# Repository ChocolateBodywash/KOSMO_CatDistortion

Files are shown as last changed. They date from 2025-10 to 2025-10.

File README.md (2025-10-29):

## KOSMO Format Cat Distortion 

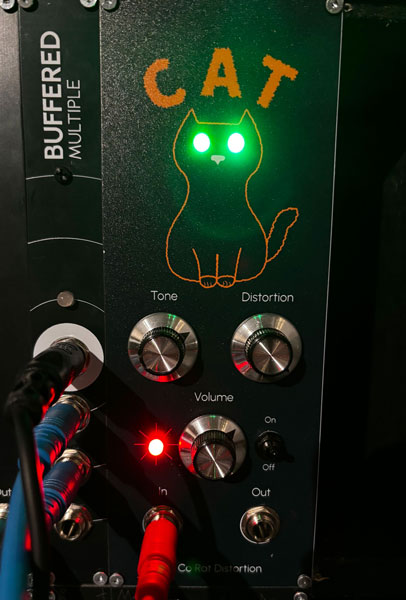
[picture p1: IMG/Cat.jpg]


A KOSMO format of a PROCO Rat distortion pedal.

I love the PROCO RAT Distortion, so I adapted it for Synth DIY.

I’ve always loved the RAT, so I reworked it for Synth DIY. If you want the deep dive into how the circuit works, check out this excellent breakdown:
https://www.electrosmash.com/proco-rat

For this version, I swapped the original op-amp for a more common TL072. The clipping circuit also got an upgrade, the diodes were replaced with LEDs, which double as glowing cat eyes on the panel. They're actually part of the circuit, not just for show. Different colours will have different forward voltages and thus may effect the sound (although I haven't tested this).

The front panel design was created using JLCPCB's colour silkscreen option, which is only avalible with easyEDA. My Kicad files are just one static colour.

Note: Because I'm not entirely sure what I'm doing, the maximum output level might be a bit much. This has a useful side effect though, it can bring guitar level to synth level.

---
Note: This was created by a hobbyist with no formal engineering training outside various late night YouTube binges. 
I’ve confirmed these designs to work but I make no guarantees on the design working efficiently.. or working at all.

Additional credit: Analog Output (Richard Holmes) for footprint libraries and front panel templates.

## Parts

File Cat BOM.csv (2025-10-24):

Reference | Value | Datasheet | Package | Qty
C1,C2 | 47uF | ~ | Electrolytic Capacitor | 2
C3,C4,C5,C6 | 0.1uF | ~ | Ceramic Disc Capacitor | 4
C7,C9 | 4.7uF | ~ | Electrolytic Capacitor | 2
C8 | 100pf | ~ | Ceramic Disc Capacitor | 1
C10 | 1nF | ~ | Box Style Film Capacitor | 1
C11,C15 | 1uF | ~ | Electrolytic Capacitor | 3
C17 | 1uF | ~ | Box Style Film Capacitor
C12,C14 | 22nF | ~ | Box Style Film Capacitor | 2
C13 | 3.3nF | ~ | Box Style Film Capacitor | 1
C16 | 2.2uF | ~ | Electrolytic Capacitor | 1
C18 | 47pF | ~ | Ceramic Disc Capacitor | 1
D1,D2 | 1N5819 | http://www.vishay.com/docs/88525/1n5817.pdf | Diode_THT:D_DO-41_SOD81_P10.16mm_Horizontal | 2
D3,D4,D5 | LED | ~ | LED 5.0mm (I used green for the eyes. These are part of the cliping stage different colours may have different effects) | 3
E1 | Conn_02x05_Pin | ~ | Pins_2x05_2.54mm_TH_EurorackPower_Shrouded | 1
J1 | In | ~ | Jack_6.35mm | 1
J2,J3 | Conn_01x06 | ~ | Connector_PinHeader_2.54mm:PinHeader_1x06_P2.54mm_Vertical | 2
J4 | Out | ~ | Jack_6.35mm | 1
Q2 | 2N5458 | https://my.centralsemi.com/datasheets/2N3819.PDF | Package_TO_SOT_THT:TO-92L_Inline_Wide | 1
R1,R2 | 10 | ~ | Metal Film 1/4 Resistor | 2
R3 | 560 | ~ | Metal Film 1/4 Resistor | 1
R4,R9,R19,R20,R22 | 1K | ~ | Metal Film 1/4 Resistor | 5
R5,R8,R11 | 1M | ~ | Metal Film 1/4 Resistor | 3
R6,R7,R14,R15 | 100K | ~ | Metal Film 1/4 Resistor | 4
R10 | 1.5K | ~ | Metal Film 1/4 Resistor | 1
R12,R17 | 10K | ~ | Metal Film 1/4 Resistor | 2
R13 | 47 | ~ | Metal Film 1/4 Resistor | 1
R16 | 3K | ~ | Metal Film 1/4 Resistor | 1
R18 | 470R | ~ | Metal Film 1/4 Resistor | 1
R21 | 22K | ~ | Metal Film 1/4 Resistor | 1
SW1 | SW_DPDT_x2 | ~ | DPDT switch | 1
U1 | TL072 | http://www.ti.com/lit/ds/symlink/tl071.pdf | DIP-8_W7.62mm | 1
VR1 | A100K Dist | ~ | Potentiometer_Alpha_RD901F-40-00D_Single_Vertical | 1
VR2 | A100K Tone | ~ | Potentiometer_Alpha_RD901F-40-00D_Single_Vertical | 1
VR3 | A100K Vol | ~ | Potentiometer_Alpha_RD901F-40-00D_Single_Vertical | 1

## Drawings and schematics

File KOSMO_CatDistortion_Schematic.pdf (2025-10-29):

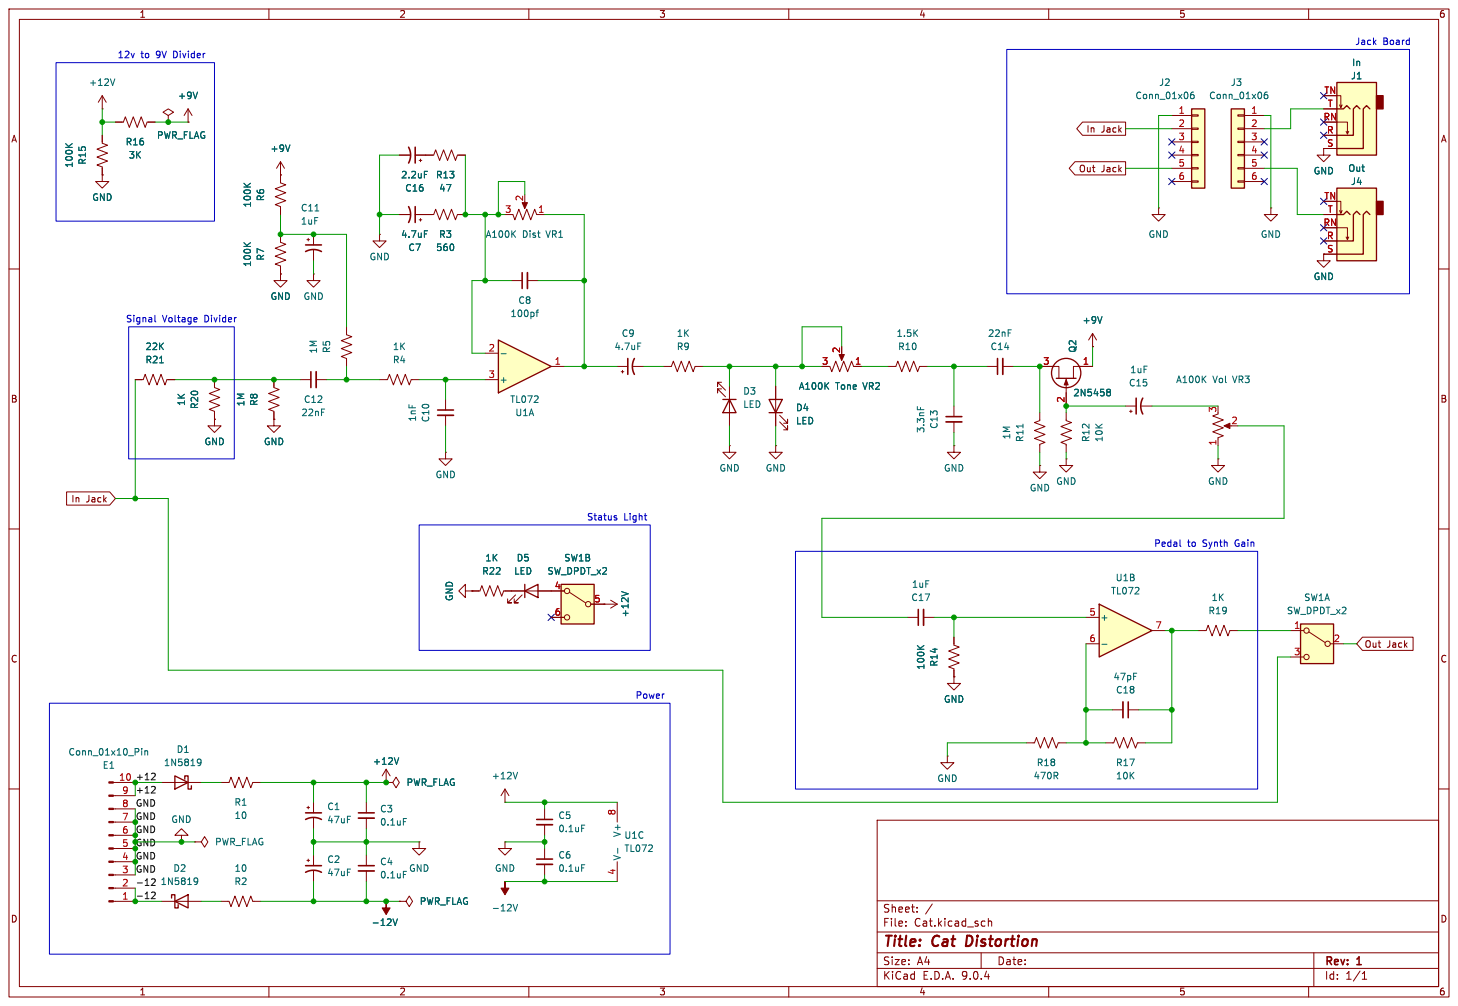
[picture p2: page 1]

Jack Board Pedal to Synth Gain
J4 Out C18

In Jack GND GND GND
PWR_FLAG R16

File: Cat.kicad_sch Sheet: /
Id: 1/1 Title: Cat Distortion

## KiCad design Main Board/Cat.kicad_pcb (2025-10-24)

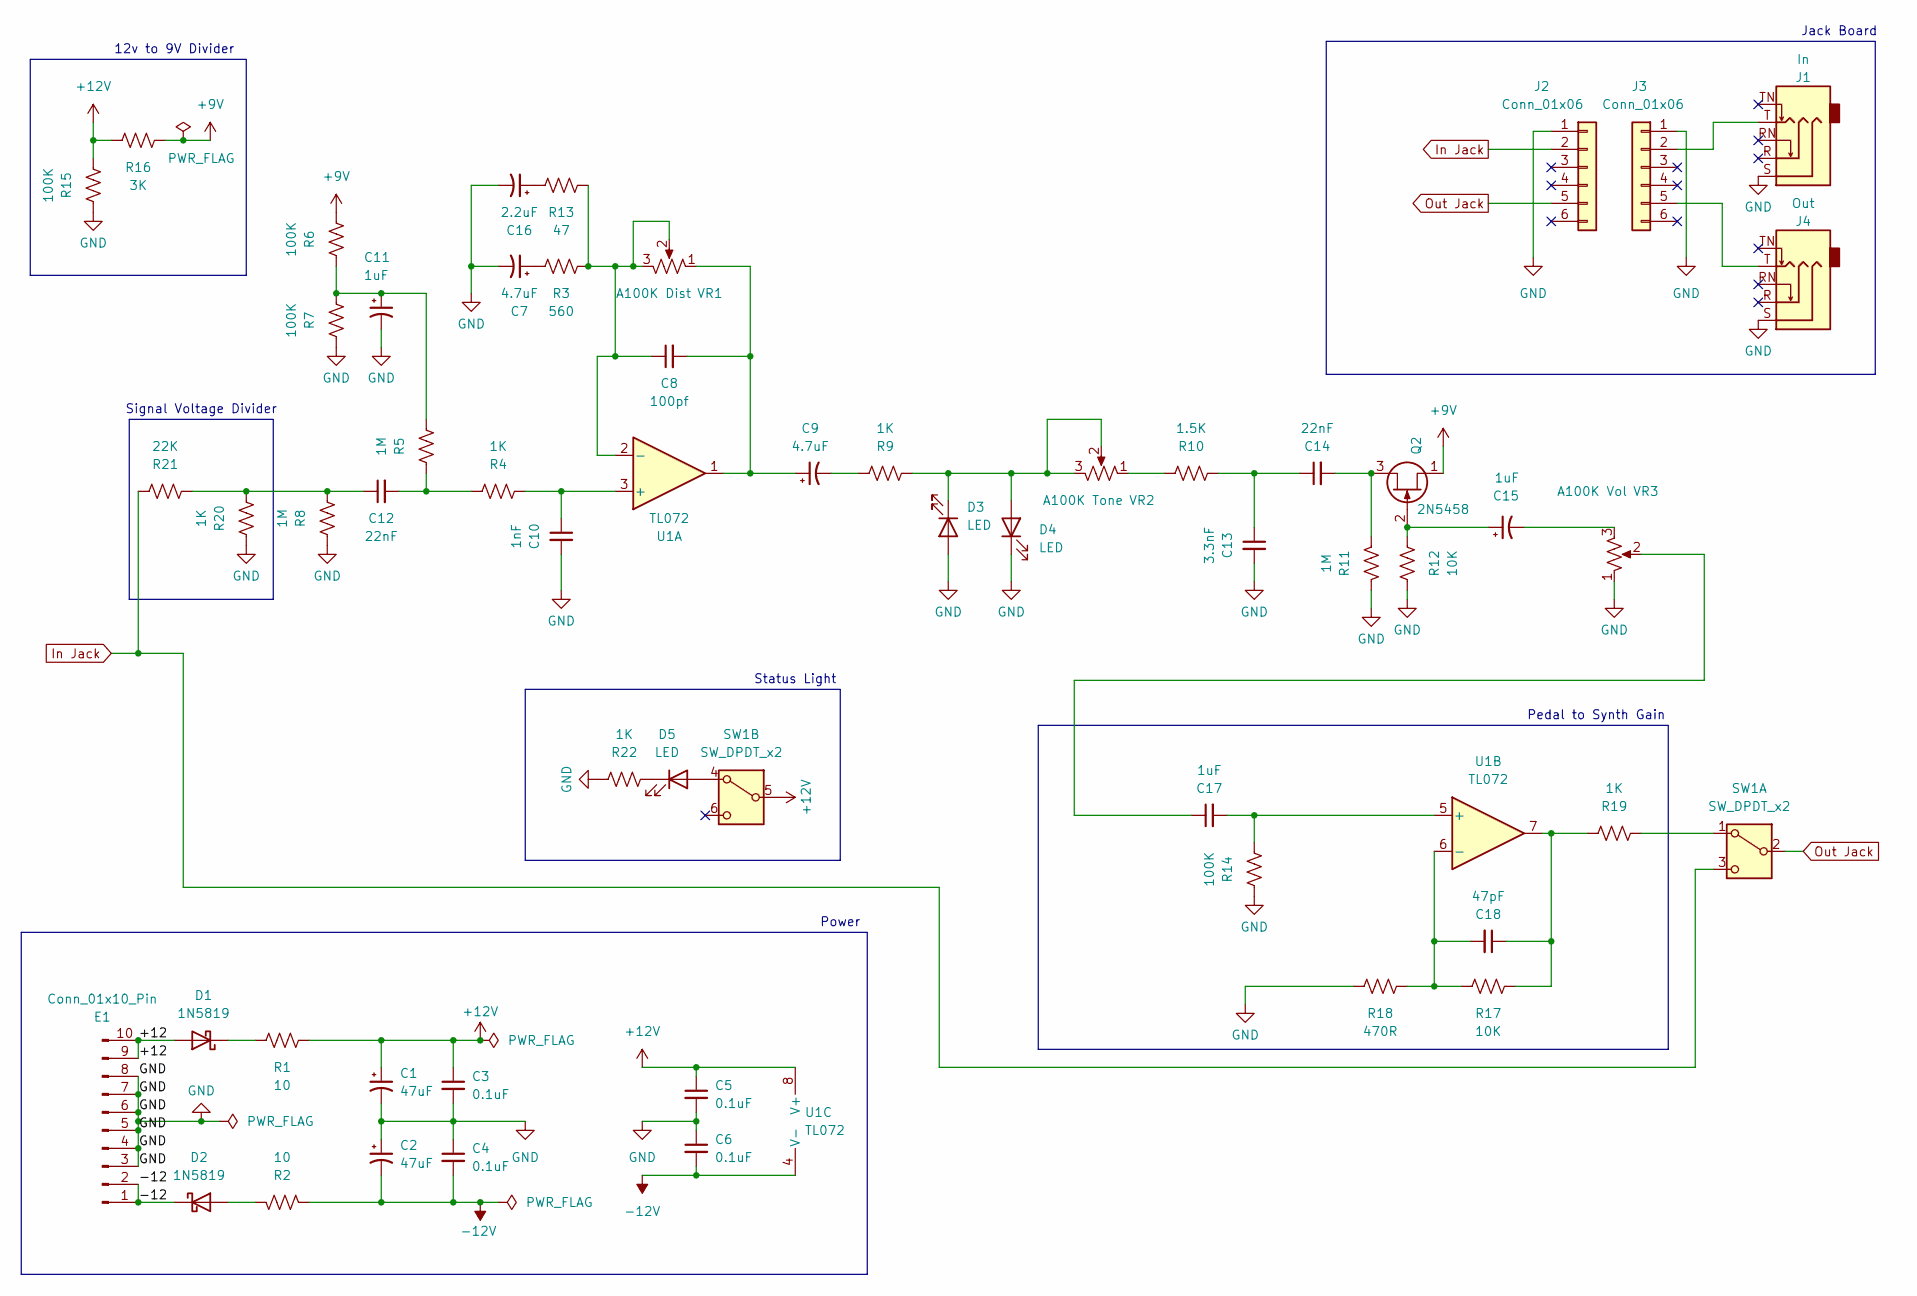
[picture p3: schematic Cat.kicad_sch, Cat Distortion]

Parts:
C1, C2: 47uF; CP_Radial_D5.0mm_P2.50mm
C3, C4, C5, C6: 0.1uF; C_Disc_D3.0mm_W1.6mm_P2.50mm
C7, C9: 4.7uF; CP_Radial_D5.0mm_P2.50mm
C8: 100pf; C_Disc_D3.0mm_W1.6mm_P2.50mm
C10: 1nF; C_Rect_L7.2mm_W2.5mm_P5.00mm_FKS2_FKP2_MKS2_MKP2
C11, C15: 1uF; CP_Radial_D5.0mm_P2.50mm
C12, C14: 22nF; C_Rect_L7.2mm_W2.5mm_P5.00mm_FKS2_FKP2_MKS2_MKP2
C13: 3.3nF; C_Rect_L7.2mm_W2.5mm_P5.00mm_FKS2_FKP2_MKS2_MKP2
C16: 2.2uF; CP_Radial_D5.0mm_P2.50mm
C17: 1uF; C_Rect_L7.2mm_W2.5mm_P5.00mm_FKS2_FKP2_MKS2_MKP2
C18: 47pF; C_Disc_D3.0mm_W1.6mm_P2.50mm
D1, D2: 1N5819; D_DO-41_SOD81_P10.16mm_Horizontal
D3, D4, D5: LED; LED_D5.0mm
E1: Conn_01x10_Pin; Pins_2x05_2.54mm_TH_EurorackPower_Shrouded
J1: In; Jack_6.35mm_PJ_629HAN
J2, J3: Conn_01x06; PinHeader_1x06_P2.54mm_Vertical_Centre
J4: Out; Jack_6.35mm_PJ_629HAN
Q2: 2N5458; TO-92L_Inline_Wide
R1, R2: 10; R_Axial_DIN0207_L6.3mm_D2.5mm_P10.16mm_Horizontal
R3: 560; R_Axial_DIN0207_L6.3mm_D2.5mm_P10.16mm_Horizontal
R4, R9, R19, R20, R22: 1K; R_Axial_DIN0207_L6.3mm_D2.5mm_P10.16mm_Horizontal
R5, R8, R11: 1M; R_Axial_DIN0207_L6.3mm_D2.5mm_P10.16mm_Horizontal
R6, R7, R14, R15: 100K; R_Axial_DIN0207_L6.3mm_D2.5mm_P10.16mm_Horizontal
R10: 1.5K; R_Axial_DIN0207_L6.3mm_D2.5mm_P10.16mm_Horizontal
R12, R17: 10K; R_Axial_DIN0207_L6.3mm_D2.5mm_P10.16mm_Horizontal
R13: 47; R_Axial_DIN0207_L6.3mm_D2.5mm_P10.16mm_Horizontal
R16: 3K; R_Axial_DIN0207_L6.3mm_D2.5mm_P10.16mm_Horizontal
R18: 470R; R_Axial_DIN0207_L6.3mm_D2.5mm_P10.16mm_Horizontal
R21: 22K; R_Axial_DIN0207_L6.3mm_D2.5mm_P10.16mm_Horizontal
SW1: SW_DPDT_x2; DPDT-toggle-switch-1M-seriesx
U1: TL072; DIP-8_W7.62mm_Socket_LongPads
VR1: A100K Dist; Potentiometer_Alpha_RD901F-40-00D_Single_Vertical
VR2: A100K Tone; Potentiometer_Alpha_RD901F-40-00D_Single_Vertical
VR3: A100K Vol; Potentiometer_Alpha_RD901F-40-00D_Single_Vertical

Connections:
+9V: Q2.1 (D), R6.1, R16.2
+12V: C1.1, C3.1, C5.1, R1.2, R15.1, R16.1, SW1.5 (B), U1.8 (V+)
-12V: C2.2, C4.2, C6.2, R2.2, U1.4 (V-)
/+12: D1.2 (A), E1.9, E1.10
/-12: D2.1 (K), E1.1, E1.2
GND: C1.2, C2.1, C3.2, C4.1, C5.2, C6.1, C7.2, C10.2, C11.2, C13.2, C16.2, D3.2 (A), D4.1 (K), E1.3, E1.4, E1.5, E1.6, E1.7, E1.8, J1.S, J2.1, J3.1, J4.S, R7.2, R8.2, R11.1, R12.1, R14.2, R15.2, R18.1, R20.2, R22.2, VR3.1
In Jack: J2.2, R21.2, SW1.3 (C)
unnamed: C7.1, R3.1
unnamed: C8.2, C9.1, U1.1, VR1.1
unnamed: C9.2, R9.2
unnamed: C11.1, R5.1, R6.2, R7.1
unnamed: C12.1, R8.1, R20.1, R21.1
unnamed: C12.2, R4.2, R5.2
unnamed: C13.1, C14.1, R10.1
unnamed: C15.2, VR3.3
unnamed: C16.1, R13.1
unnamed: C17.1, VR3.2
unnamed: C18.1, R17.2, R19.2, U1.7
unnamed: D1.1 (K), R1.1
unnamed: D2.2 (A), R2.1
unnamed: D3.1 (K), D4.2 (A), R9.1, VR2.2, VR2.3
unnamed: D5.2 (A), SW1.4 (A)
unnamed: D5.1 (K), R22.1
unnamed: J1.T, J3.2
unnamed: J3.5, J4.T
unnamed: C15.1, Q2.2 (G), R12.2
unnamed: C14.2, Q2.3 (S), R11.2
unnamed: R10.2, VR2.1
unnamed: R19.1, SW1.1 (A)
unnamed: C10.1, R4.1, U1.3 (+)
unnamed: C8.1, R3.2, R13.2, U1.2 (-), VR1.2, VR1.3
unnamed: C17.2, R14.1, U1.5 (+)
unnamed: C18.2, R17.1, R18.2, U1.6 (-)
Out Jack: J2.5, SW1.2 (B)

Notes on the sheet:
Pedal to Synth Gain
12v to 9V Divider
Status Light
Signal Voltage Divider
Jack Board
Power

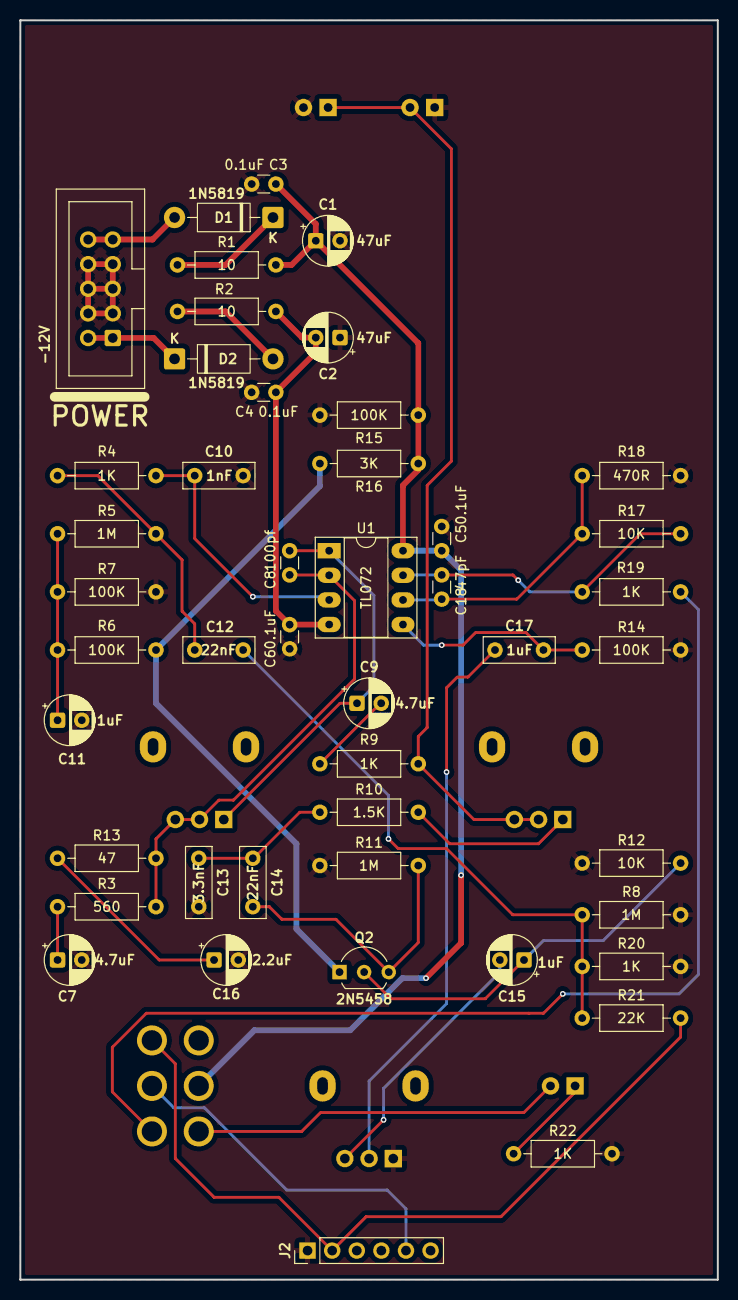
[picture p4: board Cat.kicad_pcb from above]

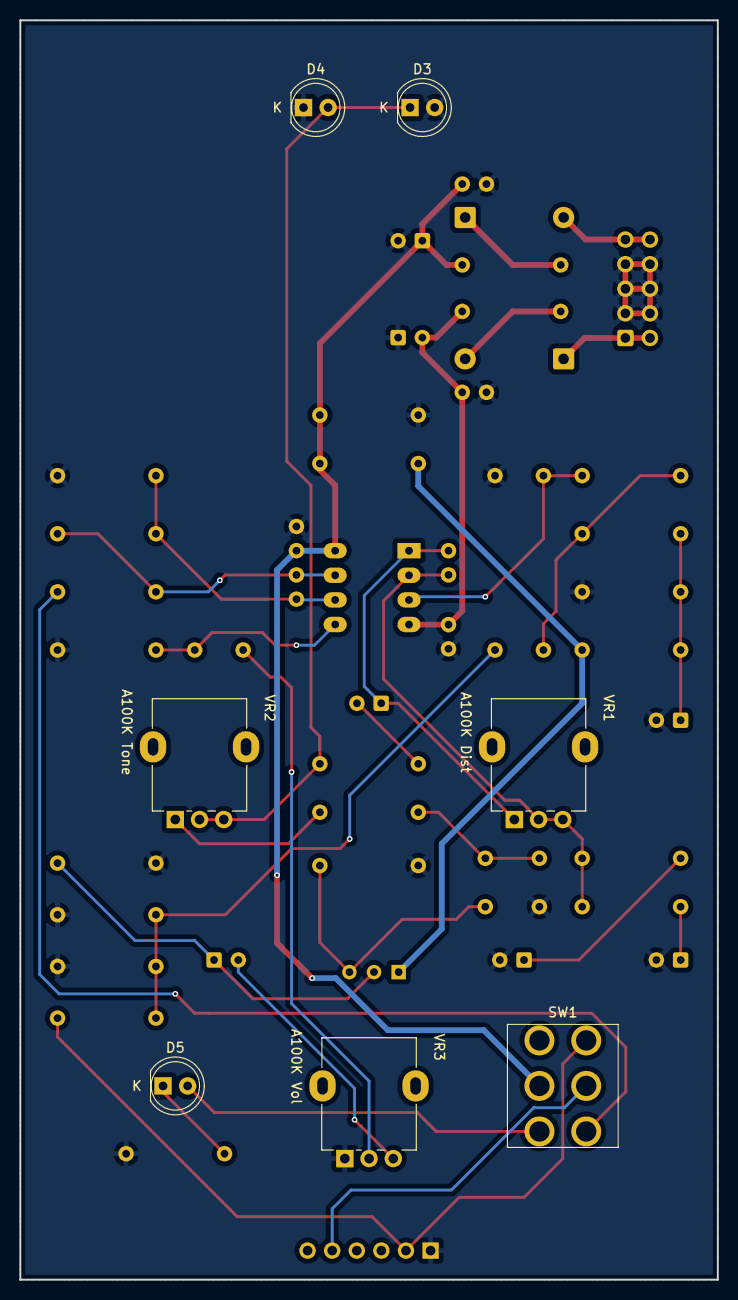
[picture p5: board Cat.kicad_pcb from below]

Board: 2 copper layers, 72.0 x 130.0 mm, 53 parts (7 on the bottom side), 32 nets.

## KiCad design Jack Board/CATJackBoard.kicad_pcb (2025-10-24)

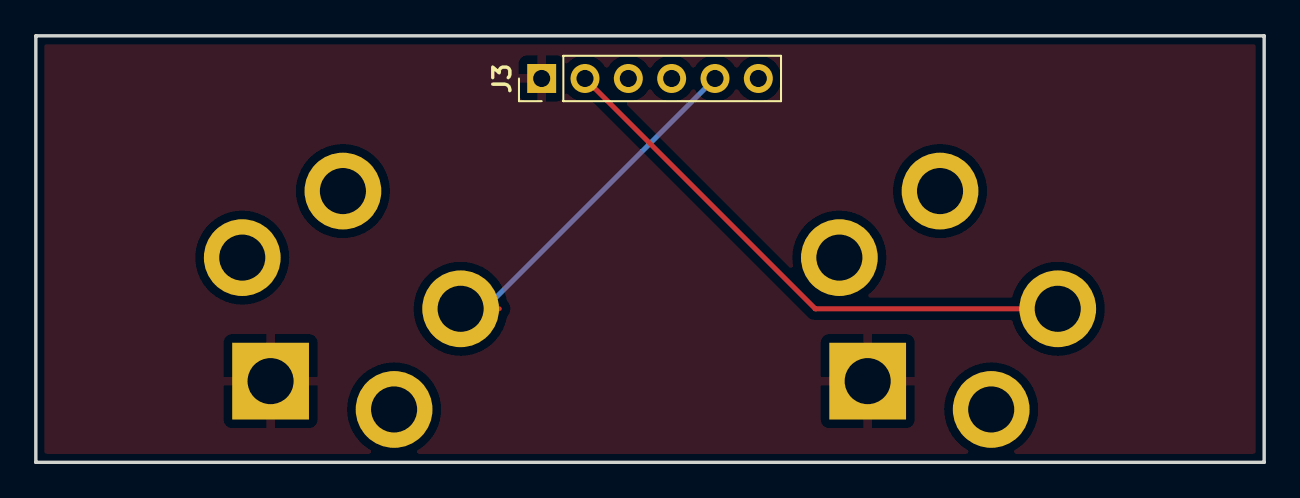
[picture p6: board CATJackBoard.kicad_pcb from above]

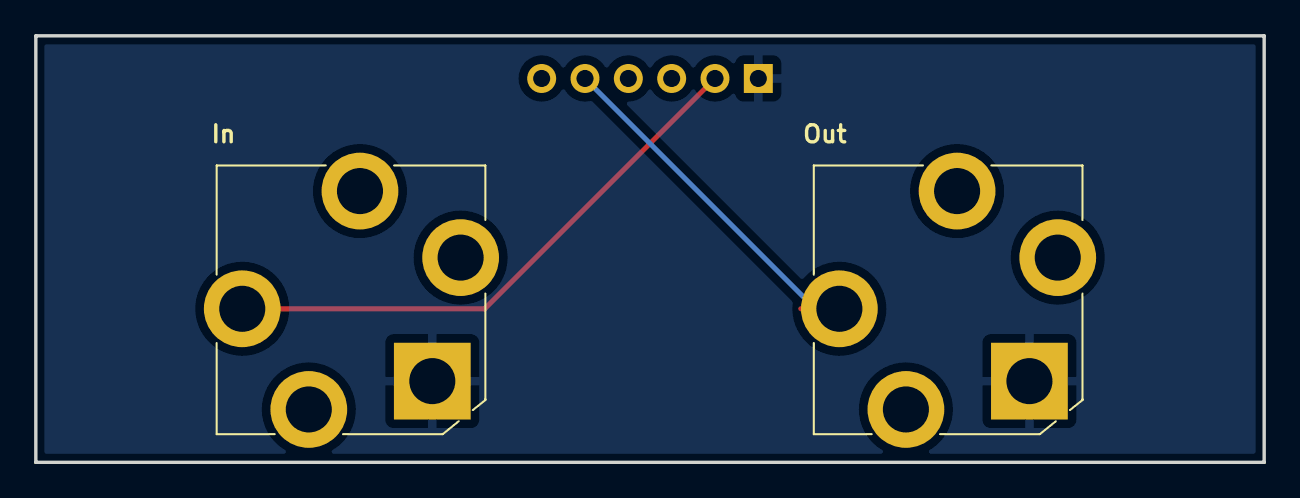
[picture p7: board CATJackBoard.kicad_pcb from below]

Board: 2 copper layers, 72.0 x 25.0 mm, 3 parts (2 on the bottom side), 3 nets.

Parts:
J1: In; Jack_6.35mm_PJ_629HAN
J3: Conn_01x06; PinHeader_1x06_P2.54mm_Vertical
J4: Out; Jack_6.35mm_PJ_629HAN

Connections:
GND: J1.S, J3.1, J4.S
unnamed: J1.T, J3.2
unnamed: J3.5, J4.T

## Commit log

2025-10-24 Create Cat BOM.csv
    [Cat BOM.csv]
2025-10-29 Upload Schematics
